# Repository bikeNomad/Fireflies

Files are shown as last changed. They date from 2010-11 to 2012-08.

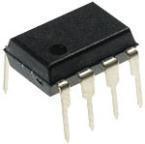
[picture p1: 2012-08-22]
attiny.jpg

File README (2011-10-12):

This is Xander Hudson's <mailto:jar@synoptic.org> excellent "Jar of Fireflies" project, with some code modifications and a couple of board designs in EAGLE.

The main code modification is the addition of darkness detection (using a photoresistor).

Original project: <http://www.instructables.com/id/Jar-of-Fireflies/>

License: Creative Commons (by)

Please credit Xander Hudson, the original author.

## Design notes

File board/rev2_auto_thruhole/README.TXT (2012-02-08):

README.TXT	This file
firefly2_auto_thruhole.GBL	Bottom Copper
firefly2_auto_thruhole.GBS	Bottom Soldermask
firefly2_auto_thruhole.GTL	Top Copper
firefly2_auto_thruhole.GTO	Top Silk
firefly2_auto_thruhole.GTS	Top Soldermask
firefly2_auto_thruhole.TXT	Excellon drill file

Ned Konz
ned@bike-nomad.com

Black soldermask

white top silkscreen

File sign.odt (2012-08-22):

Open source design

http://github.com/bikeNomad/Fireflies

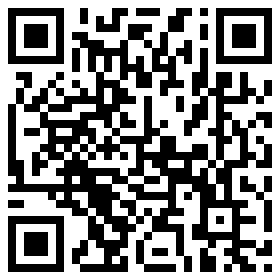
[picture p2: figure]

# Jar of Fireflies Kits $10

(cash only, please)

Battery included!

Six LEDs play actual firefly "songs" when it gets dark

Help Jigsaw Renaissance!

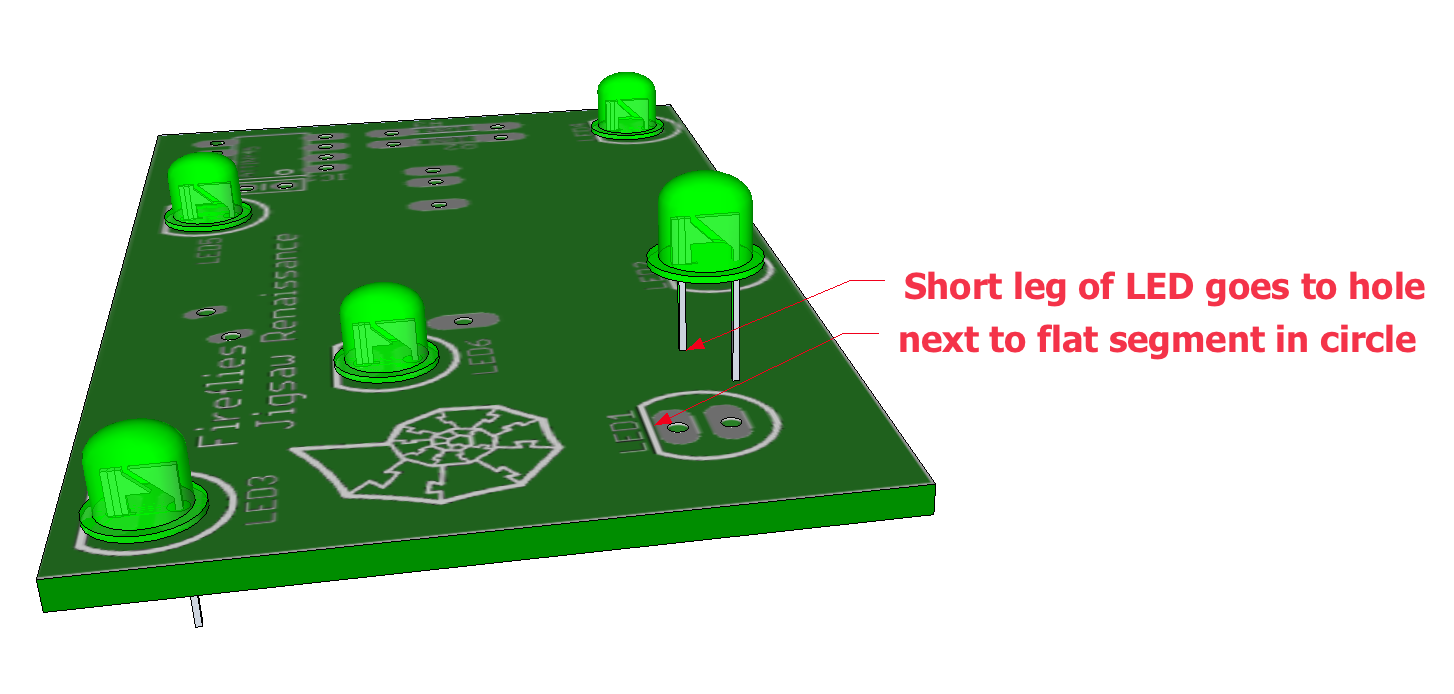
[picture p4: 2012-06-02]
led_insertion.png

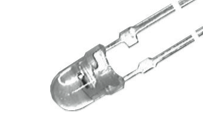
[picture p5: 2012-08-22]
tept4400.tiff

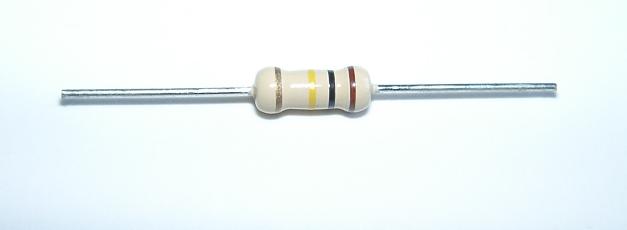
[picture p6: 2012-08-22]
Resistor.JPG

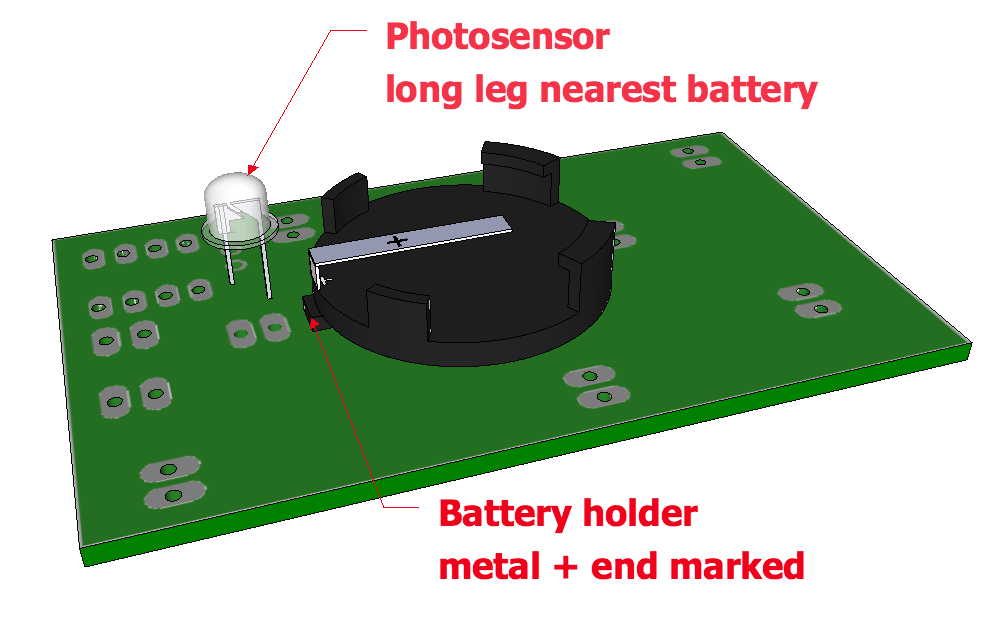
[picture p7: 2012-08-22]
underside.tiff

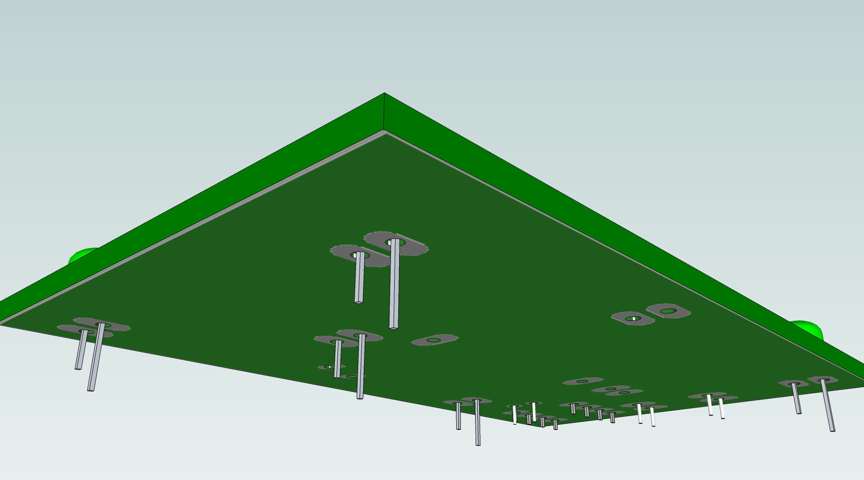
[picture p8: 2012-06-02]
leads.png

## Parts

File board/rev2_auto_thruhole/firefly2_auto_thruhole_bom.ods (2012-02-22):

 |  |  |  |  | board 2.54x1.54 inches
 |  |  |  |  |  | mouser | digikey | paid | per board
on hand | boards on hand | Qty | Value | Device | Parts
5 | 5 | 1 |  | BATTERY20PTH | BAT1 | 122-2520-gr | bs-7-nd | $0.76 | $0.76 | 20mm holes/0.787 in | eagle 122-2520-gr | 0.7874015748
450 | 75 | 6 |  | LED3MM | LED1, LED2, LED3, LED4, LED5, LED6 | 859-LTL-4231N-1 |  | $0.05 | $0.31 | T-1
60 | 30 | 2 | 100 | RESISTORPTH1 | R2, R3 |  |  | $0.04 | $0.08 | 0.3 spacing
2 | 2 | 1 | 100n | CAPPTH_SMALL2 | C1 |  |  | $0.10 | $0.10 | 0.1 spacing
25 | 25 | 1 | ATTINY45 | ATTINY25DIP08 | IC1 | 556-ATTINY85V10PU (http://www.mouser.com/Search/ProductDetail.aspx) |  | $1.30 | $1.30 |  | attiny85 is only 0.08 more
30 | 30 | 1 |  | amb light sensor |  | TEPT4400 |  | $0.05 | $0.05
30 | 30 | 1 | board |  | gold phoenix |  |  | $2.81 | $2.81
6 | 6 | 1 | battery | 2032 |  |  |  | $0.40 | $0.40
 |  |  |  |  | parts total |  |  |  | $5.81
 |  |  |  |  |  |  |  |  |  | gold phoenix | vil reset | 0.3
 |  |  |  |  |  |  |  |  |  |  | reset pullup | 3.00E+004 | 6.00E+004
 |  |  |  |  |  |  |  |  |  |  | min cdS | 12857.1428571429 | 25714.2857142857

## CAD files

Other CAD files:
LED_jig.skp
bareboard.skp
board.skp
board~.skp

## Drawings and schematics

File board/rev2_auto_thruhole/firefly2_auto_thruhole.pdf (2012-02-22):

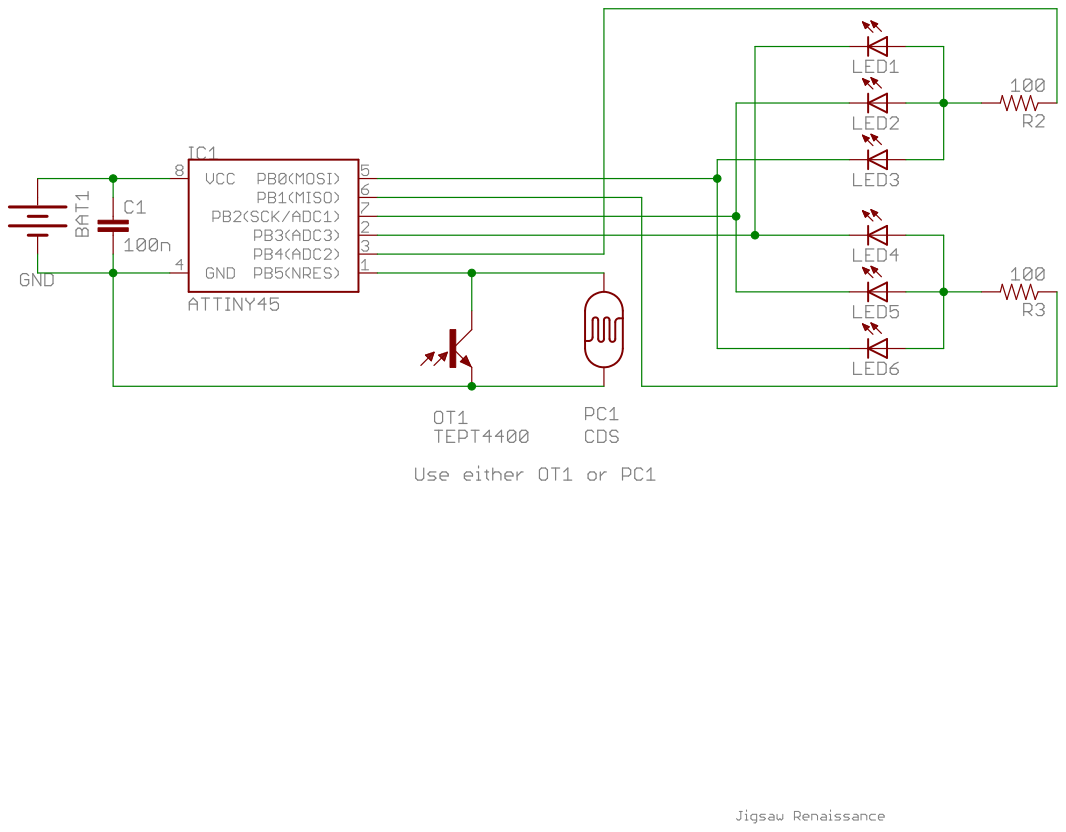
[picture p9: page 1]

2/21/12 10:08 PM f=1.04 /Users/ned/src/Fireflies/board/firefly2_auto_thruhole.sch (Sheet: 1/1)

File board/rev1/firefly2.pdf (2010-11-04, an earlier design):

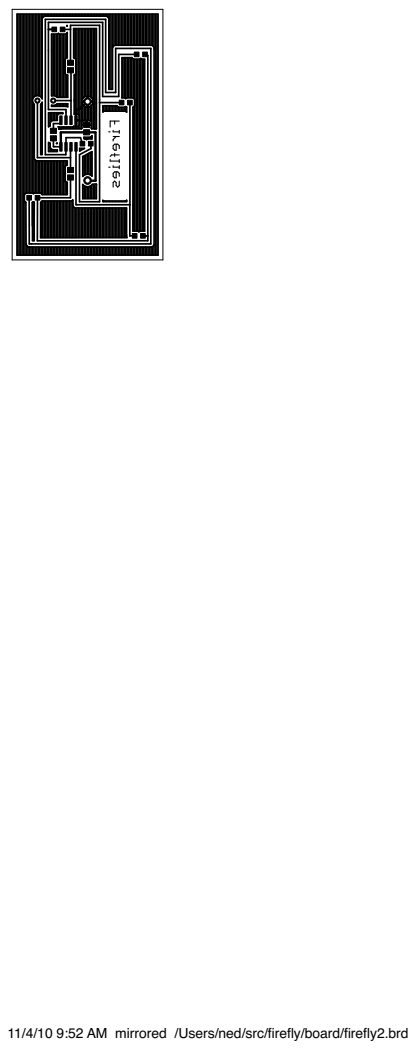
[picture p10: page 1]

11/4/10 9:52 AM mirrored /Users/ned/src/firefly/board/firefly2.brd

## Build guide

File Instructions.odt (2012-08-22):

# Jar of Fireflies Circuit Board

Board design by Ned Konz ned@bike-nomad.com

Design files and code available at http://github.com/bikeNomad/Fireflies

This is Xander Hudson's (jar@synoptic.org) excellent "Jar of Fireflies" project, with some code modifications and a couple of board designs in EAGLE.

The main code modification is the addition of darkness detection (using a photoresistor).

Original project: <http://www.instructables.com/id/Jar-of-Fireflies/>

License: Creative Commons (by)

Please credit Xander Hudson, the original author.

# Kit Contents

Qty. | Part

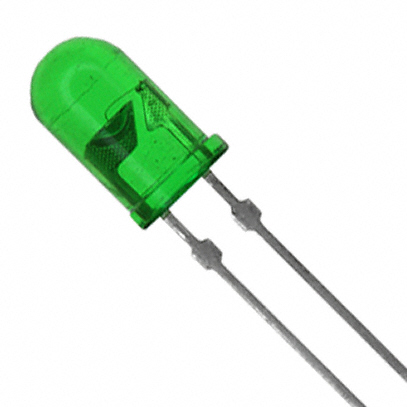
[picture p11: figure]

6 | Green LEDs


1 | Photosensor, TEPT-4400 (looks like the LEDs but is clear)
1 | Battery holder 20mm diameter
1 | Ceramic capacitor (0.1uF/100nF)
1 | Battery (CR2016 or CR2032)
1 | Circuit Board, blank


1 | ATtiny45 or ATtiny85 microcontroller, programmed with Jar of Fireflies code

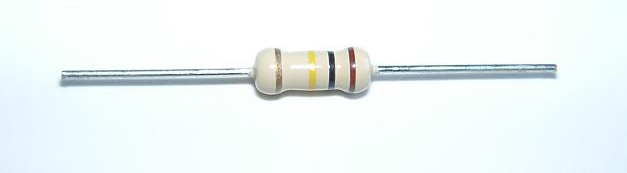
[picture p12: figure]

2 | 1/8 or 1/4 watt resistors, 100 to 150 ohms

# Assembly

1. Identify the top side of the circuit board. This is the side with the white printing.
2. Bend the leads of one of the two resistors at right angles to the body. From the top side of the board, insert the resistor into the correct holes (its direction doesn't matter), spread the legs on the bottom side of the board, turn the board over and solder both legs. Cut the legs near to where you soldered.
3. Repeat with the other resistor.

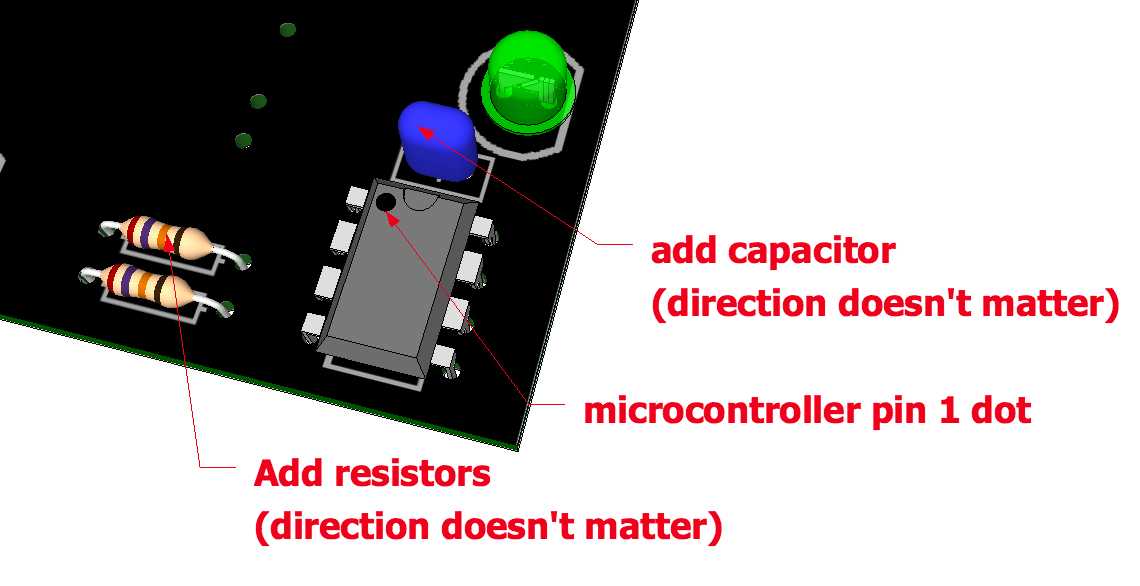
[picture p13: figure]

4. Insert and solder the capacitor. Its direction doesn't matter.
5. Insert and solder the 8 pin microcontroller, making sure that the dot that marks its pin #1 is above the dot marked on the circuit board.

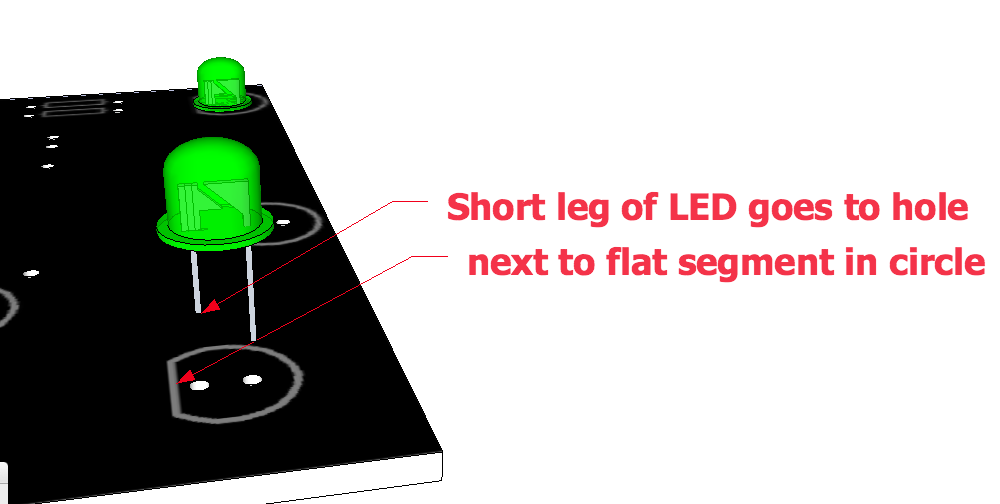
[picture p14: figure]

6. Insert and solder the six LEDs into the top side of the board (the side with the white printing). The shorter leg of the LEDs goes into the hole nearest the flat side of the flattened circle (see diagram).


7. Turn the board over. Insert and solder the photosensor, inserting the longer leg through the hole nearest the battery holder.
8. Cut the plastic pins off the bottom of the battery holder.
9. Insert and solder the battery holder, making sure that the + end (the end with the metal clip) is next to the photosensor.
10. Insert the battery into the holder, making sure that the side marked + is up and in contact with the metal clip.
11. Test the board by covering the light sensor and waiting a bit to see the LEDs flash.

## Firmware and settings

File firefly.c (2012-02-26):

#include <avr/io.h>
#include <avr/wdt.h>
#include <avr/interrupt.h>
#include <avr/pgmspace.h>
#include <avr/sleep.h>
#include <avr/power.h>
#include "firefly.h"

const prog_uint8_t about[] = "Jar of Fireflies\n"
            "Design and Implementation by Xander Hudson (jar@synoptic.org)\n"
            "Idea and Inspiration by Kayobi Tierney\n"
            "Special thanks to Katie Horn for getting me to think about electronics";
const prog_uint8_t version[] = "$Revision: 1.41 $ $Date: 2007/01/10 04:35:55 $";

#if USE_PHOTOTRANSISTOR
// PIN_F (reset/PB5) used as ADC0, thus an input
#  define LEDS_OFF ~(_BV(PIN_A) | _BV(PIN_B) | _BV(PIN_F))
#  define DDRB_DEFAULT ~(_BV(PIN_F))
#else
#  define LEDS_OFF ~(_BV(PIN_A) | _BV(PIN_B))
#  define DDRB_DEFAULT 0xFF
#endif

#define WATCHDOG_OK  WDTCR |= _BV(WDIE)

uint8_t pickapin (uint8_t);
const Song *pickasong (void);
uint8_t randwaitval (void);
uint8_t randbits (uint8_t);
uint8_t pickmaster (void);
uint8_t randscaleval (void);
void showbootup (void);

#define ch1playing ((volatile io_reg*) _SFR_MEM_ADDR(FLAGS0))->b0
#define ch1resting ((volatile io_reg*) _SFR_MEM_ADDR(FLAGS0))->b1
#define ch2playing ((volatile io_reg*) _SFR_MEM_ADDR(FLAGS0))->b2
#define ch2resting ((volatile io_reg*) _SFR_MEM_ADDR(FLAGS0))->b3
#define need_mood ((volatile io_reg*) _SFR_MEM_ADDR(FLAGS0))->b4
#define ch1noteready ((volatile io_reg*) _SFR_MEM_ADDR(FLAGS0))->b6
#define ch2noteready ((volatile io_reg*) _SFR_MEM_ADDR(FLAGS0))->b7

volatile uint8_t ch1restcount;
volatile uint8_t ch2restcount;

volatile uint8_t ch1nextnote;
volatile uint8_t ch2nextnote;

volatile uint8_t ch1scale;
volatile uint8_t ch2scale;
volatile uint8_t ch1nextscale;
volatile uint8_t ch2nextscale;

register uint8_t ch1bright asm ("r2");
register uint8_t ch2bright asm ("r3");
register uint8_t ch1err asm ("r4");
register uint8_t ch2err asm ("r5");
register uint8_t ch1pin asm ("r6");
register uint8_t ch2pin asm ("r7");
register uint8_t portval asm ("r8");

/*  mood, mood_count                                                */
/*  This value changes slowly over time and is added to the random          */
/*  wait timer.  Having this change slowly adds a sense of 'moodiness'      */
/*  where the fireflys will go through phases of being active or lethargic. */

uint8_t mood = 2;
uint16_t mood_count = 30;   // WDT cycles before changing mood

volatile uint8_t masterpinmask;

static void still_dark(void);
static void wait_for_dark(void);
#if USE_PHOTOTRANSISTOR
volatile uint8_t waiting_for_dark;	// true if in the "wait for dark" state.
volatile uint8_t is_dark;	        // true if it still seems to be dark.
volatile uint8_t force_dark;
static uint8_t read_adc(uint8_t);
#else
#   define is_dark          1
#   define waiting_for_dark 0
#endif

#if READ_TEMPERATURE
static uint8_t read_temperature(void);
#endif

/* Intentionally crash the program leaving a visual clue.  The  */
/* watchdog should then come and reboot us.                     */
#define FREAKOUT  for (;;) {PORTB = LEDS_OFF; PORTB = ~LEDS_OFF; } 


ISR(WDT_vect) {
    still_dark();
	if (ch1resting && (--ch1restcount == 0)) ch1resting = 0;
	if (ch2resting && (--ch2restcount == 0)) ch2resting = 0;
	if (!need_mood && (--mood_count == 0)) need_mood = 1;
}

ISR(TIM0_COMPA_vect) {
    static uint8_t x;

    if (waiting_for_dark)
		return;

    // Do this right up front so there's no jitter from all
    // the complex logic to follow.
    PORTB=portval;
    
    // x rolls around to zero naturally every 256 cycles.  It's on
    // the start of one of these cycles that we change the note that
    // we're playing.
    if ( x-- == 0 ) {
        if (ch1playing) {
            // We're playing a song. Is there another note
            // for us to read? If not, shut down.
            if (ch1noteready) {  
                ch1bright = ch1nextnote;
                ch1noteready = 0;
            } else {
                // We ran out of notes to play.
                ch1bright = 0;
                // Has our rest duration been chosen yet?
                if (ch1restcount != 0) {  
                    ch1playing = 0;   
                    ch1resting = 1;
                } // if not, go through the loop again.
            }
        } else if (!ch1resting && ch1noteready) {  
                // We weren't playing a song but now we see
                // that we're clear to start.
                ch1bright = ch1nextnote;
                ch1noteready = 0;
                ch1playing = 1;
        }

        if (ch2playing) {
            if (ch2noteready) {
                ch2bright = ch2nextnote;
                ch2noteready = 0;
            } else {
                ch2bright = 0;
                // Has our rest duration been chosen yet?
                if (ch2restcount != 0) {  
                    ch2playing = 0;   
                    ch2resting = 1;
                } // if not, go through the loop again.
            }
        } else if (!ch2resting && ch2noteready) {
                ch2bright = ch2nextnote;
                ch2noteready = 0;
                ch2playing = 1;
        }
        
        // These shouldn't be neccessary since the error
        // value should wrap around to 0 after 256 cycles
        // anyways, but leave these in until I'm able to
        // verify that.

        if (ch1playing) ch1err = 0;
        if (ch2playing) ch2err = 0;

        // If either channel is playing, turn on the master pin.    
        if (ch1playing || ch2playing) 
            portval = LEDS_OFF | masterpinmask;
        else 
            portval = LEDS_OFF;    // lights off.
    }

    // Here is where we do the actual PWM, which is defined as
    // an inline assembler macro.
    if ( ch1playing ) pwm(ch1bright, ch1err, portval, ch1pin);
    if ( ch2playing ) pwm(ch2bright, ch2err, portval, ch2pin);

}


/*
 * Do all the startup-time peripheral initializations.
 */
static void
ioinit(void)
{ 
    wdt_enable(WDTO_500MS);   // Set watchdog timeout

	WATCHDOG_OK; 	// Set watchdog to generate interrupt.

    // Set all pins as outputs.
    // Drive PIN_A and PIN_B low, everybody else high.
    DDRB = DDRB_DEFAULT;
    PORTB= LEDS_OFF;

    PRR |= _BV(PRTIM1);  // Turn off Timer1 to save power.
    PRR |= _BV(PRUSI);   // Turn off USI clock
    PRR |= _BV(PRADC);   // Turn off ADC

#if USE_PHOTOTRANSISTOR
    // disable digital input buffer on ADC pin to reduce power consumption
    DIDR0 = _BV(ADC0D);
#endif

    /*
     * Set up the 8-bit timer 0.
     *
     * Timer0 will be set in CTC up with a prescalar of 8 and an OCR0A copmare 
     * value of 25. 
     * A core clock frequency of 8mhz / 4 means we should get an interrupt 
     * frequency of about 39hz.  (freq = 976.563 / (OCR0A))
     */

    TCCR0A = _BV(WGM01);  // Set CTC mode, timer counts 0 - OCRA

    //TCCR0B = _BV(CS01) | _BV(CS00); // Clock/64
    //TCCR0B = _BV(CS00); // Clock
    TCCR0B = _BV(CS01); // Clock/8
    OCR0A = 25;

    clock_prescale_set(clock_div_4);

    TIMSK = _BV(OCIE0A);

    WATCHDOG_OK;
}

void showbootup (void) {
    // This is a bit of a mystery
    // Wasn't able to find out why the program would
    // break if I tried to something like 
    //       Song *ch1song = &bootsong;
    const Song *ch1song = bootsongs[0];
    uint16_t ch1noteptr;
    uint8_t mpin,cpin;

    const uint8_t masterpins[] = { _BV(PIN_A), _BV(PIN_B) };
    const uint8_t ch1pins[] = { _BV(PIN_C), _BV(PIN_D), _BV(PIN_E) };

    cli();
    ch1restcount = 2;
    ch1resting = 1; 
    sei();

    for (mpin=0; mpin < sizeof(masterpins)/sizeof(uint8_t); mpin++) {
        masterpinmask = masterpins[mpin];

        for (cpin=0; cpin < sizeof(ch1pins)/sizeof(uint8_t); cpin++) {
            ch1pin = ch1pins[cpin];

            for (ch1noteptr=0; ch1noteptr < ch1song->notecount; ch1noteptr++) {
                ch1nextnote = pgm_read_byte(&ch1song->notes[ch1noteptr++]);
                ch1noteready = 1;

                while (ch1noteready == 1) {
                    WATCHDOG_OK;
                    set_sleep_mode(SLEEP_MODE_IDLE);
                    sleep_mode();
                }
            }
        }
    }
    
    cli();
    ch1restcount = 1;   
    sei();

    while (ch1playing) {
        WATCHDOG_OK;
        set_sleep_mode(SLEEP_MODE_IDLE);
        sleep_mode();
    }
    
}

uint8_t randwaitval (void) {
#if PHOTOSHOOT
    return mood + randbits(3) + randbits(3)  + randbits(3); 
#else
    return mood + randbits(4) + randbits(4) + randbits(3) + 
           randbits(2) + randbits(2) - randbits(3); 
#endif
}

uint8_t randscaleval (void) {

#if BRIGHTER
    return (randbits(6) + randbits(5) + randbits(5) + randbits(4) + 
            randbits(3) + 54);
#elif PHOTOSHOOT
    // for photoshoot
    return (randbits(6) + randbits(5) + randbits(4) + randbits(3) + 
            randbits(2) + 34);
#else 
    /* Returns bell-like distributed random value between %23 - 69% centered
        around 46% */
    return (randbits(6) + randbits(5) + randbits(4) + randbits(3) + 
            randbits(2) + 58);
#endif
}

/* pickapin -- choose a pin to play a song on.       */
/*    Basically either C, D, or E.                   */
/*    We take as an argument the pin of the other    */
/*    channel so that we can ensure we don't return  */
/*    a channel currently in use.                    */
uint8_t pickapin (uint8_t inuse) {
    uint8_t pinmask;
    uint8_t myrand = randbits(8);

    /* faster way to do (randbits(8) % 3) */
    myrand = ((uint16_t)((myrand << 1) + myrand)) >> 8;
    
    // 0, 1, and 2 should be only possible values.
    // if we pick a pinmask equal to exclude parameter, fall through
    // to next option (or wrap around to start via default)
    switch ( myrand ) {
        case ( 0 ) : pinmask = _BV(PIN_C); if (pinmask != inuse) break;
        case ( 1 ) : pinmask = _BV(PIN_D); if (pinmask != inuse) break;
        case ( 2 ) : pinmask = _BV(PIN_E); if (pinmask != inuse) break;
        default    : pinmask = _BV(PIN_C); break;
    }
    return pinmask;
}

/* pickmaster -- Pick which pin is going to be master. */
/*    Basically either A or B.  I tend to prefer       */
/*    that we switch masterpins frequently, so I've    */
/*    stacked the deck so that there's simply a        */
/*    1 in 8 chance we keep the same masterpin.        */
uint8_t pickmaster (void) {
    static uint8_t ticker;
    if (randbits(3) == 0) {
        // 1 in 8 chance we don't switch masterpins.  
		// in this case, return the value we gave last time.
        return ( (ticker & 1) ? _BV(PIN_A) : _BV(PIN_B) );
    } else {
        // switch masterpins
        return ( (++ticker & 1) ? _BV(PIN_A) : _BV(PIN_B) );
    }
}


/* randbits -- implementation of linear feedback shift register. */
uint8_t randbits(uint8_t bits)
{
    static uint16_t lfsr = RANDOM_SEED;

    if (lfsr == 0)
        FREAKOUT;

    if ((lfsr & 0x8000) == 0)
        lfsr = lfsr << 1;
    else {
        lfsr = lfsr << 1;
        lfsr = lfsr ^ 0x1D87;
    }

    // Mask out the bits we want.
    return ((lfsr & 0xFF) & pgm_read_byte(&bitmasks[bits]));
}

const Song *pickasong(void)
{
    // when the number of songs to choose from is a power of two, the
    // optimizer makes this quite fast.  Otherwise it can take hundreds of
    // cycles to
    // do the multiplication.
    return songs[(randbits(8) * (sizeof (songs) / sizeof (Song *))) >> 8];
}


#if (USE_PHOTOTRANSISTOR || READ_TEMPERATURE)

static uint8_t read_adc(uint8_t muxreg)
{
	// enable and set up ADC
    PRR &= ~_BV(PRADC);      // turn on the ADC power
    ADMUX = muxreg | _BV(ADLAR);    // left-justified result
    // ensure that ADC is not busy converting
    loop_until_bit_is_clear(ADCSRA, ADSC);
    ADCSRA = _BV(ADEN) | _BV(ADSC);      // enable ADC and start conversion
    // wait until done converting
	loop_until_bit_is_clear(ADCSRA, ADSC);

	// get ADC result (high 8 bits)
    uint8_t retval = ADCH;

	// disable ADC
    ADCSRA &= ~_BV(ADEN);    // disable ADC
    PRR |= _BV(PRADC);        // turn off the ADC power

    return retval;
}

#endif


#if USE_PHOTOTRANSISTOR

// called from WDT ISR
// sets is_dark if dark enough
// phototransistor between RESET line and GND
static void still_dark(void)
{
    static uint8_t debounce = DARK_DEBOUNCE;

	// read state
    uint8_t photocell = read_adc(PHOTOTRANSISTOR_ADC);  // Vcc as VRef, no conn to AREF.

    if ((photocell > DARK_MINIMUM) || force_dark)
    {
        if (!debounce--)
        {
            debounce = DARK_DEBOUNCE;
            is_dark = 1;
        }
    }
    else
    {
        debounce = DARK_DEBOUNCE;
        is_dark = 0;
    }
    return;
}

static void wait_for_dark(void)
{
    waiting_for_dark = 1;
    TIMSK = 0;  // disable timer 0 compare interrupt
    while (!is_dark) {
        WATCHDOG_OK;
        set_sleep_mode(SLEEP_MODE_PWR_DOWN);
        sleep_mode();
        // wake from WDT interrupt.
    }
    TIMSK = _BV(OCIE0A);    // enable timer 0 interrupt
    waiting_for_dark = 0;
}

#else   /* !USE_PHOTOTRANSISTOR */
static void still_dark(void)        { }
static void wait_for_dark(void)     { }
#endif  /* USE_PHOTOTRANSISTOR */

#if READ_TEMPERATURE

static uint8_t read_temperature(void)
{
    return read_adc(_BV(REFS1) | 0x0F); // 1.1V ref, no external bypass, select temp channel
}

#endif


// do the old main loop, but only as long as it's still dark.
void lighted_fireflies(void)
{
    static const Song *ch1song;
    static const Song *ch2song;
    static uint16_t ch1noteptr;
    static uint16_t ch2noteptr;
    static uint8_t temp;

    // main loop.
    while (is_dark) {
        /* If we have a channel playing, take care of its */
        /* housekeeping first.  */
        if (ch1playing || ch2playing) {
            /* If channel is playing but doesn't have its next note */
            /* loaded, load it.  */

            if (ch1playing && !ch1noteready) {
                if (ch1noteptr != ch1song->notecount) {

                    temp = pgm_read_byte(&ch1song->notes[ch1noteptr++]);
                    temp = ((uint16_t) (ch1scale * temp)) >> 8;

                    cli();
                    ch1nextnote = temp;
                    ch1noteready = 1;
                    sei();

                    continue;   // Loop over from start.
                }               // Else end of song.
            }

            if (ch2playing && !ch2noteready) {
                if (ch2noteptr != ch2song->notecount) {
                    temp = pgm_read_byte(&ch2song->notes[ch2noteptr++]);
                    temp = ((uint16_t) (ch2scale * temp)) >> 8;

                    cli();
                    ch2nextnote = temp;
                    ch2noteready = 1;
                    sei();

                    continue;   // Loop over from start.
                }               // Else end of song.
            }

            /* If a channel is playing a song and its restcount is 0, */
            /* we need to pick a new random restcount for it.  */

            if (ch1playing && ch1restcount == 0) {
                temp = randwaitval();
                cli();
                ch1restcount = temp;
                sei();
                continue;       // Loop over from start.
            }

            if (ch2playing && ch2restcount == 0) {
                temp = randwaitval();
                cli();
                ch2restcount = temp;
                sei();
                continue;       // Loop over from start.
            }
        }

        /* If channel is done resting and waiting for a song to */
        /* be queued up, select a song for it.  */
        if (!ch1playing && !ch1resting && !ch1noteready) {
            ch1song = pickasong();
            ch1noteptr = 0;

            ch1pin = pickapin(ch2pin);

            // Now pick a random scaling value so the brightness
            // varies over time.
            ch1scale = randscaleval();

            temp = pgm_read_byte(&ch1song->notes[ch1noteptr++]);
            temp = ((uint16_t) (ch1scale * temp)) >> 8;

            // If the other channel isn't playing lets reselect the
            // master pin.
            if (ch2resting)
                masterpinmask = pickmaster();

            cli();
            ch1nextnote = temp;
            ch1noteready = 1;
            sei();

            continue;           // Loop over from start.
        }

        if (!ch2playing && !ch2resting && !ch2noteready) {
            ch2song = pickasong();
            ch2noteptr = 0;

            ch2pin = pickapin(ch1pin);

            // Now pick a random scaling value so the brightness
            // varies over time.
            ch2scale = randscaleval();

            temp = pgm_read_byte(&ch2song->notes[ch2noteptr++]);
            temp = ((uint16_t) (ch2scale * temp)) >> 8;

            // If the other channel isn't playing lets reselect the
            // master pin.
            if (ch1resting)
                masterpinmask = pickmaster();

            cli();
            ch2nextnote = temp;
            ch2noteready = 1;
            sei();

            continue;           // Loop over from start.
        }

        if (need_mood) {
#if PHOTOSHOOT
            mood = 1;
#else
            mood = randbits(5) + 8;
#endif
            mood_count = 60 * 5 * 2;
            need_mood = 0;

            continue;           // Loop over from start.
        }

        WATCHDOG_OK;

        /* If both channels are resting then go to deep sleep.  */
        /* We shouldn't get to here unless all our housekeeping */
        /* work is done.  */
        if (ch1resting && ch2resting) {
            set_sleep_mode(SLEEP_MODE_PWR_DOWN);
            sleep_mode();
        }
        else {
            set_sleep_mode(SLEEP_MODE_IDLE);
            sleep_mode();
        }
    }
}


int main(void)
{
    ioinit();

    // Zero out register variables.
    ch1bright = ch2bright = ch1err = ch2err = ch1pin = ch2pin = portval = 0;
    ch1restcount = randwaitval();
    ch2restcount = randwaitval();

    // Zero out flags.
    FLAGS0 = 0;

#if USE_PHOTOTRANSISTOR
    waiting_for_dark = 0;
    is_dark = 1;
    force_dark = 1;
#endif

    sei();
    showbootup();

#if USE_PHOTOTRANSISTOR
    force_dark = 0;
#endif

    for (;;) {
        wait_for_dark();

        ch1bright = ch2bright = ch1err = ch2err = ch1pin = ch2pin = portval = 0;
        FLAGS0 = 0;
        ch1resting = 1;
        ch2resting = 1;

        lighted_fireflies();
    }
}

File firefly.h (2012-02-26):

#include "config.h"

#if !(SONG1 || SONG2)
#define SONG1 1
#endif

#ifndef RANDOM_SEED
#define RANDOM_SEED 0x5806
#endif

#include "songs/songs.h"

#include "songs/bootsong.h"

#if SONG1
#include "songs/song1a.h"
#include "songs/song1b.h"
#include "songs/song1c.h"
//#include "songs/song1d.h"  // too fast
#include "songs/song1e.h"
#endif

#if SONG2
#include "songs/song2a.h"
#include "songs/song2b.h"
#include "songs/song2c.h"
#include "songs/song2d.h"
#include "songs/song2e.h"
#include "songs/song2f.h"
#include "songs/song2g.h"
#endif

const Song *bootsongs[] = { &bootsong };

/* Keep the number of songs as a power of 2 so that the compiler       */
/* can optimize the pickasong() routine using bit shift multiplication */

const Song *songs[] = { 
#if SONG1
       &song1a, &song1a, &song1a, &song1a, &song1a,
       &song1b, &song1b, &song1b, &song1b, &song1b,
       &song1c, &song1c, &song1c,
       &song1e, &song1e, &song1e,
#endif

#if SONG2
        &song2a, 
        &song2b, &song2b,
        &song2c, &song2c, &song2c,
        &song2d, &song2d,
        &song2e, &song2e, &song2e,
        &song2f, &song2f,
        &song2g, &song2g, &song2g, 
#endif
        };

/*  The following code implements some flags using the GPIOR0 general
 *  pupose I/O register.  It's ugly, but doing it this way immediately
 *  shaved over 230 bytes off of my code.
*/

typedef struct {
    uint8_t  b0:1, 
             b1:1,
             b2:1,
             b3:1,
             b4:1,
             b5:1,
             b6:1,
             b7:1;
} io_reg;

/* Pins A and B are always driven high when playing a song.  The other pins,
 * A, D, and E are flickered on an off to drive an individual LED.
 * Due to how the circuit is constructed, only one of A or B can
 * be high at a time, meaning only the LED's directly connected them
 * are compatible with being played at the same time.
 *    The possible simultaneous combinations are 
 *    
 *    if ( A ) { A-C, A-D, A-E }
 *      else   { B-C, B-D, B-E } //B
*/

// PIN_B is PB1
#define PIN_B 1

// PIN_A is PB4/ADC2
#define PIN_A 4
#define PIN_A_ADC 2

// PB3
#define PIN_C 3
// PB2
#define PIN_D 2
// PB0
#define PIN_E 0

// PB5/ADC0/!RESET
#define PIN_F 5
#define PIN_F_ADC 0

#if USE_PHOTOTRANSISTOR
#   define PHOTOTRANSISTOR_PIN    PIN_F
#   define PHOTOTRANSISTOR_ADC    PIN_F_ADC
#endif

#define FLAGS0 GPIOR0

/* pwm(value, error, result, resultmask) 
 *   Implements 8-bit PWM with the result being a bit 
 *   (selected by resultmask) set or cleared in result. 
 *   Adopted from Bresenham's line drawing algorithm and heavily
 *   optimized.  I've also heard this called 'delta-sigma' encoding.
 *       error should return to 0 after 256 cycles.
 *       don't change 'value' until the cycle of 256 is done.
 *   If all values are kept in registers, this
 *   takes either 8 or 9 cycles to execute and consumes 20 bytes
 *   of program space.
*/
#define pwm(value, error, result, resultmask)        \
    __asm__ __volatile__ (                           \
            "mov     __tmp_reg__, %5"         "\n\t" \
            "bst     %3, 7"                   "\n\t" \
            "add     %0, %3"                  "\n\t" \
            "brvs    von_%="                  "\n\t" \
            "brts    turnon_%="               "\n\t" \
            "rjmp    turnoff_%="              "\n"   \
"von_%=:"                                     "\n\t" \
            "brts    turnoff_%="              "\n"   \
"turnon_%=:"                                  "\n\t" \
            "com     __tmp_reg__"             "\n\t" \
            "and     %1, __tmp_reg__"         "\n"   \
            "rjmp    done_%="                 "\n"   \
"turnoff_%=:"                                 "\n\t" \
            "or      %1, __tmp_reg__"         "\n\t" \
"done_%=:"                                    "\n\t" \
            : "=&r" (error), "=&r" (result)          \
            : "0" (error), "r"  (value),             \
              "1"  (result),                         \
              "r"  (resultmask)                      \
            );

/* This lookup table is used by the randbits function  */
/* to quickly generate a bitmask for a given number of */
/* requested bits.  Using this table is faster than    */
/* computing a bit mask on the fly.                    */

const prog_uint8_t bitmasks[] = { 
        0x00,
        0x01, 0x03, 0x07, 0x0F,
        0x1F, 0x3F, 0x7F, 0xFF
}; 

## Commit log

2009-12-09 turn on PIN_A after reading ADC
2010-11-04 Did PCB layout
    [calibrate.brd, firefly.brd, firefly.sch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]
2011-09-11 Added firefly2_auto board
    [firefly2_auto.brd, firefly2_auto.sch]
2011-09-11 Added Sketchup models
    [LED_jig.skp]
2011-09-11 Added CdS on RESET pin
2011-10-04 More work on BOM
    [firefly2_auto.dsn, firefly2_auto_thruhole.brd, firefly2_auto_thruhole.dsn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]
2011-10-16 Added Jigsaw logo; changed pads to long for easier soldering
    [firefly2_auto_thruhole.brd, firefly2_auto_thruhole.sch]
2012-01-09 Added photosensor
    Also generated Gerbers
    [firefly2_auto_thruhole.brd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]
2012-02-08 Added layout to CAM
    [firefly2_auto_thruhole.brd]
2012-02-14 added sketchup model
    [bareboard.skp, board.skp, board~.skp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]
2012-02-14 modified board model
    [board.skp, board~.skp]
2012-02-22 updated BOM; edited for phototransistor
    [firefly2_auto_thruhole_bom.ods]
2012-06-02 Added documentation
    2-page document with some pictures
    [board.skp, firefly2_auto_thruhole.sch]
2012-06-03 Extended instructions
    added pictures
    [board.skp, board~.skp]
